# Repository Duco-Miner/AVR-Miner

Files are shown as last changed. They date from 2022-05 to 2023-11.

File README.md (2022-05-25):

# AVR-Miner

The AVR-Miner Board forms the Slave Device controlled by the [ESP32-Miner](https://github.com/Duco-Miner/ESP32-Miner) in the DUCO-Miner Rack. The [Common Miner Baseboard](https://github.com/Duco-Miner/Common-Miner-Baseboard) uses multiple AVR-Miner Boards for Mining the Duino Coin.

These are the KiCAD Project files for the AVR-Miner Board PCB.

Please feel free to modify the design files as per your requirements. Improvements are always appreciated !!!

---
### Preview:

1) PCB View 1:

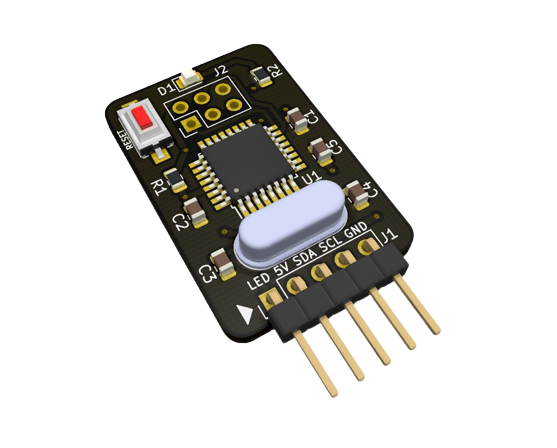
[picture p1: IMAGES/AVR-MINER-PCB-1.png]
AVR-Miner


2) PCB View 2:

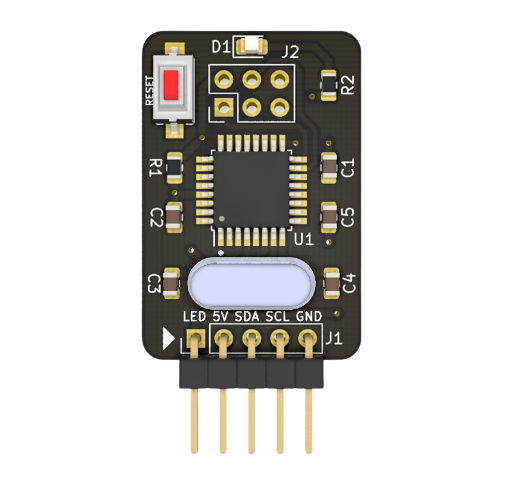
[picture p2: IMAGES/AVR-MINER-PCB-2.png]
AVR-Miner


3) PCB Front View:

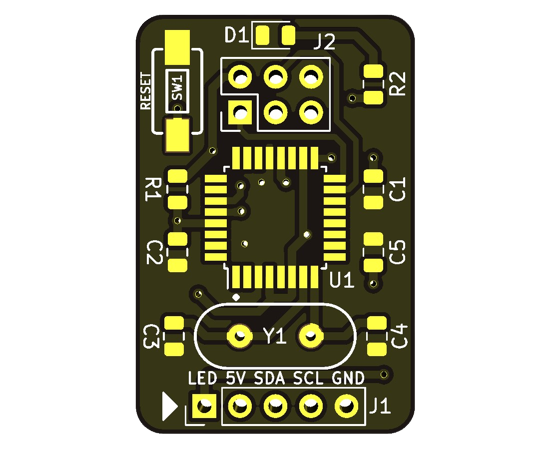
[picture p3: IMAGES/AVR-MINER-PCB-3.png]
AVR-Miner


4) PCB Back View:

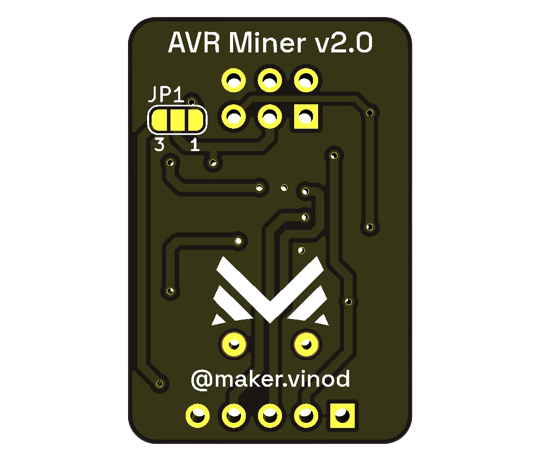
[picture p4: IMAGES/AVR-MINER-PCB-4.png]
AVR-Miner

---

### PCB Specifications:

- Layers: 2
- Size: 20mm x 30mm

---

### Components:

| Sr. No. | Component | Package | Quantity | Marking on PCB |
| :-----: | :--- | :-----: | :---: | :---: |
| 1 | Atmega328P-AU or Atmega8-AU | TQFP-32 | 1 | U1 |
| 2 | 16MHz Crystal | HC49US  | 1 | Y1 |
| 3 | 3x6x2.5mm SMD Tactile Switch | - | 1 | SW1 |
| 4 | 10uF 16V Capacitor |  0805 | 1 | C5 |
| 5 | 22pF 16V Capacitor |  0805 | 2 | C3,C4 |
| 6 | 0.1uF 16V Capacitor |  0805 | 2 | C1,C2 |
| 7 | 10k Resistor |  0805 | 1 | R1 |
| 8 | 1k Resistor |  0805 | 1 | R2 |
| 9 | 1x5 2.5mm Pin Header Male - Right Angle | - | 1 | J2 |
| 10 | LED (Blue Color) |  0805 | 1 | D1 |

---

### Supported Controllers:

|  Controller | Supported | Hash Rate (H/s) |
| :---: | :---: | :---: |
| Atmega328P-AU | ✔️ | 250-270 |
|  Atmega8-AU | ✔️ | 220-230 |

---

### Program/Code:

Please find the Code to be uploaded to AVR Miner here: [https://github.com/Duco-Miner/AVR-Miner-Code](https://github.com/Duco-Miner/AVR-Miner-Code)

---

### Additional Links:

- Check out the awesome Duino Coin Project at: [https://duinocoin.com](https://duinocoin.com)
- Duino Coin Wallet: [https://wallet.duinocoin.com](https://wallet.duinocoin.com)

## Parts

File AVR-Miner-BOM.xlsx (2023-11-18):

 |  |  | AVR-MINER BOARD BOM (Bill of Materials)
Item # | *Designator | *Qty | Manufacturer | *Mfg Part # | Description / Value | *Package/Footprint | Type | Your Instructions / Notes
1 | C1, C2 | 2 | KYOCERA AVX | KGM21NR71H104KM | Capacitor 0.1uF | 0805 | SMD
2 | C3, C4 | 2 | KEMET | C0805C220F5GAC7800 | Capacitor 22pF | 0805 | SMD
3 | C5 | 1 | Murata Electronics | GRM21BR61C106KE15K | Capacitor 10uF | 0805 | SMD
4 | D1 | 1 | Lite-On Inc. | LTST-C171TBKT | LED Blue | 0805 | SMD
5 | J1 | 1 | Sullins Connector Solutions | PRPC005SGAN-M71RC | 2.54mm Pin Header Male 1x05 | PinHeader_1x05_P2.54mm | PTH
8 | R1 | 1 | Stackpole Electronics Inc | RMCF0805FT10K0 | 10k | Resistor_SMD:R_0805_2012Metric | SMD
9 | R2 | 1 | Stackpole Electronics Inc | RMCF0805FT1K00 | 1k | 0805 | SMD
10 | SW1 | 1 | C&K | PTS636 SM25J SMTR LFS | SMD TACTILE SWITCH | TACTILE_SWITCH_SMD_6.0X3.5MM | SMD
11 | U1 | 1 | Microchip Technology | ATMEGA328P-AU | ATmega328P-AU | TQFP-32 | SMD
12 | Y1 | 1 | ECS Inc. | ECS-160-18-4X-CKM | 16MHz | HC49US | PTH

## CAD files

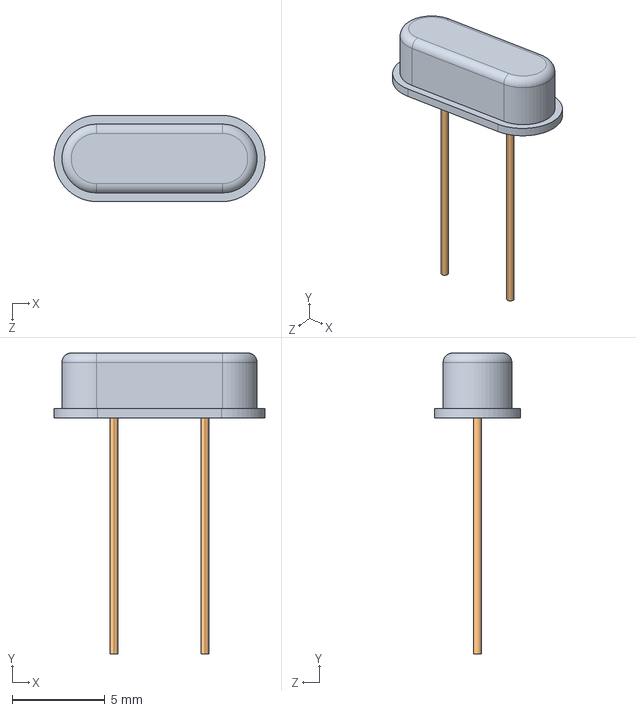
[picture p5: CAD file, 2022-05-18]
3D/ECS-160-20-4DN.STEP
11.4 x 16.2 x 4.65 mm

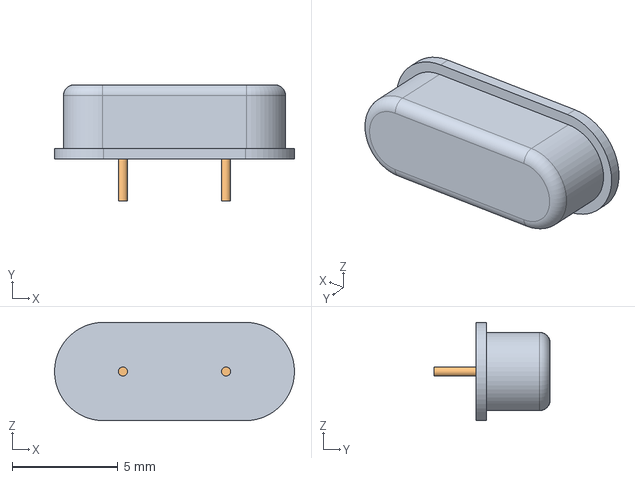
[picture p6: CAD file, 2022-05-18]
3D/ECS-160-20-4DN v2_.step
11.4 x 5.50 x 4.65 mm

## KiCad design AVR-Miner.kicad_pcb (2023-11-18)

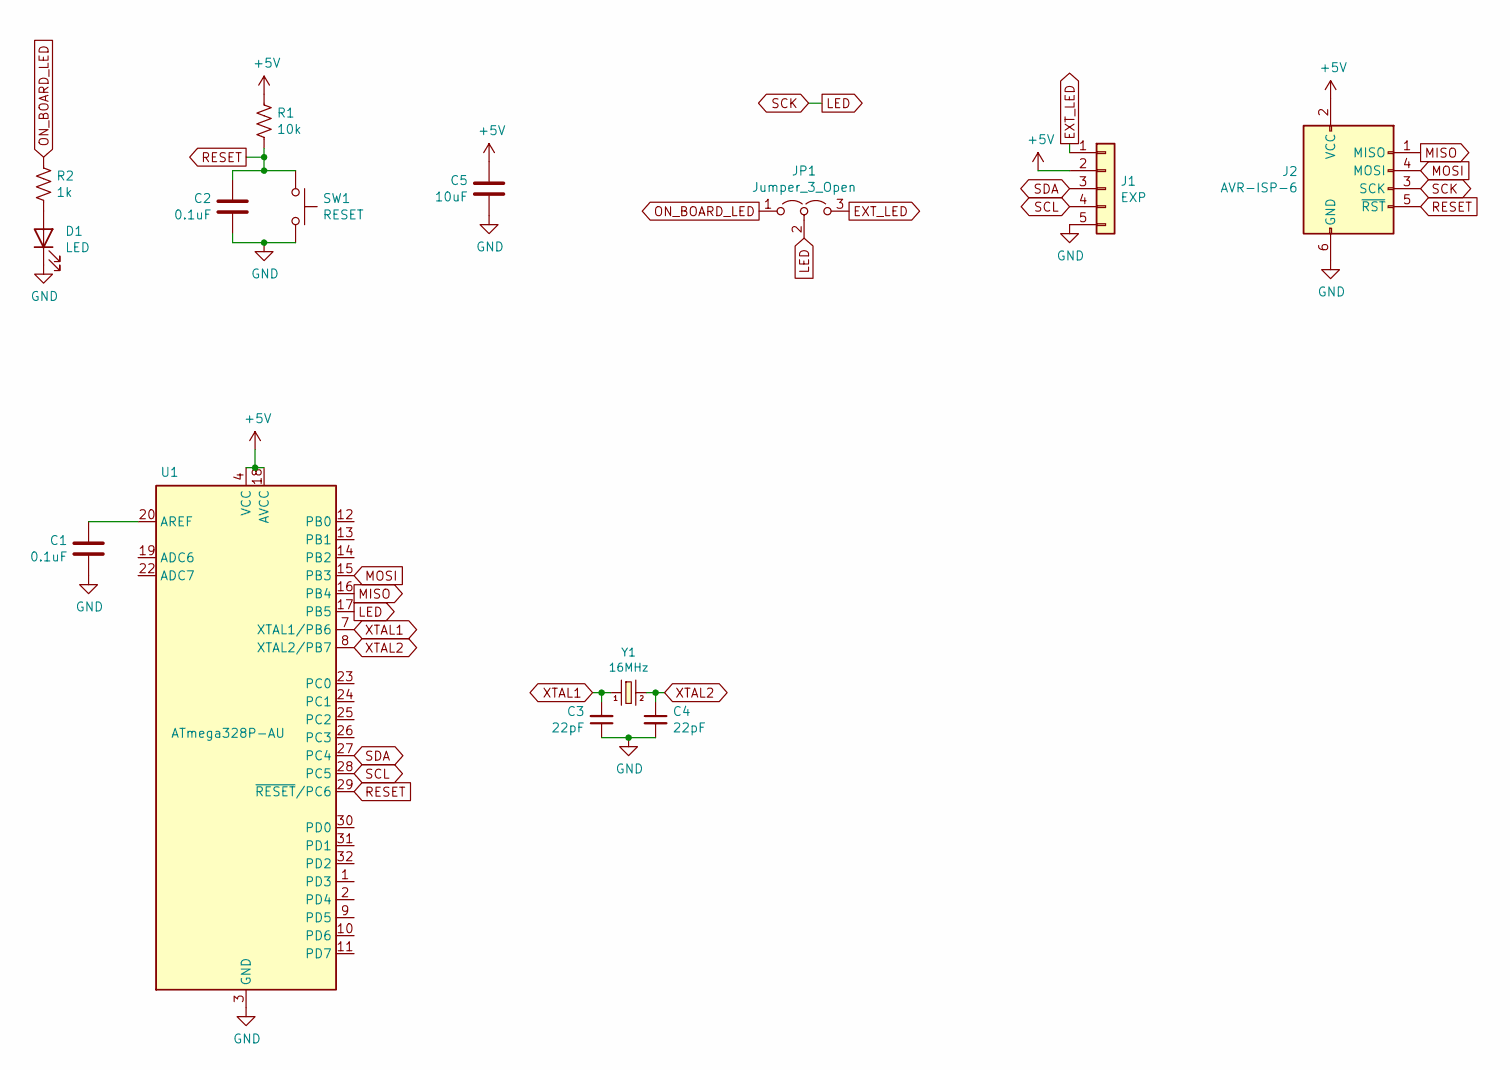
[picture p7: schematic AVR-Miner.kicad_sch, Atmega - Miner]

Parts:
C1, C2: 0.1uF; C_0805_2012Metric
C3, C4: 22pF; C_0805_2012Metric
C5: 10uF; C_0805_2012Metric
D1: LED; LED_0805_2012Metric
J1: EXP; PinHeader_1x05_P2.54mm_Vertical
J2: AVR-ISP-6; PinHeader_2x03_P2.54mm_Vertical
JP1: Jumper_3_Open; SolderJumper-3_P1.3mm_Open_RoundedPad1.0x1.5mm_NumberLabels
R1: 10k; R_0805_2012Metric
R2: 1k; R_0805_2012Metric
SW1: RESET; TACTILE_SWITCH_SMD_6.0X3.5MM
U1: ATmega328P-AU; TQFP-32_7x7mm_P0.8mm
Y1: 16MHz; HC49US

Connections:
+5V: C5.2, J1.2, J2.2 (VCC), R1.1, U1.4 (VCC), U1.6 (VCC), U1.18 (AVCC)
EXT_LED: J1.1, JP1.3 (B)
GND: C1.1, C2.1, C3.1, C4.2, C5.1, D1.1 (K), J1.5, J2.6 (GND), SW1.2, U1.3 (GND), U1.5 (GND), U1.21 (GND)
LED: J2.3 (SCK), JP1.2 (C), U1.17 (PB5)
MISO: J2.1 (MISO), U1.16 (PB4)
MOSI: J2.4 (MOSI), U1.15 (PB3)
unnamed: D1.2 (A), R2.2
unnamed: C1.2, U1.20 (AREF)
ON_BOARD_LED: JP1.1 (A), R2.1
RESET: C2.2, J2.5 (~RST), R1.2, SW1.1, U1.29 (~RESET/PC6)
SCL: J1.4, U1.28 (PC5)
SDA: J1.3, U1.27 (PC4)
XTAL1: C3.2, U1.7 (XTAL1/PB6), Y1.1
XTAL2: C4.1, U1.8 (XTAL2/PB7), Y1.2

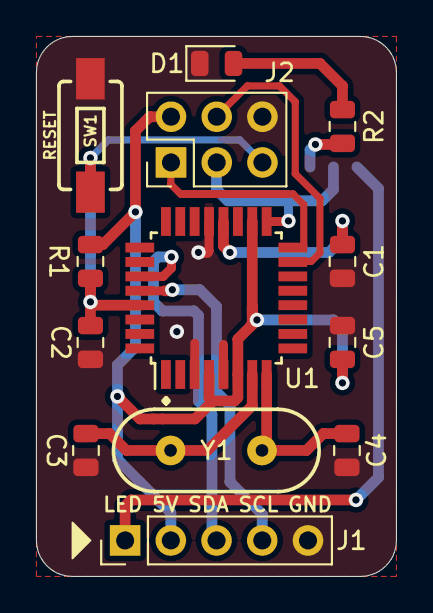
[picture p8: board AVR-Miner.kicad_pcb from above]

Board: 2 copper layers, 20.0 x 30.0 mm, 14 parts (1 on the bottom side), 14 nets.

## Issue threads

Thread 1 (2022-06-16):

missing symbols

gionag, 2022-06-16:
please post the symbol and footprint library for parts that has no candidates on kicad.
thanks

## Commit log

2022-05-18 Added v1.0.0
    [AVR-Miner.kicad_pcb, AVR-Miner.sch, ECS-160-20-4DN v2_.step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]
2022-05-18 Added v2.0.0
    [AVR-Miner.kicad_pcb, AVR-Miner.sch]
2022-05-25 Updated README & added Images for the PCB
2023-11-18 Updated project files for KiCad 7 & Added Gerber files
    [AVR-Miner-BOM.xlsx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]
